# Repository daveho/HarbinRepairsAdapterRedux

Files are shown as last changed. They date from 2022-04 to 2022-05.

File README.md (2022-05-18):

# Improved Harbin Repairs Adapter PCBs

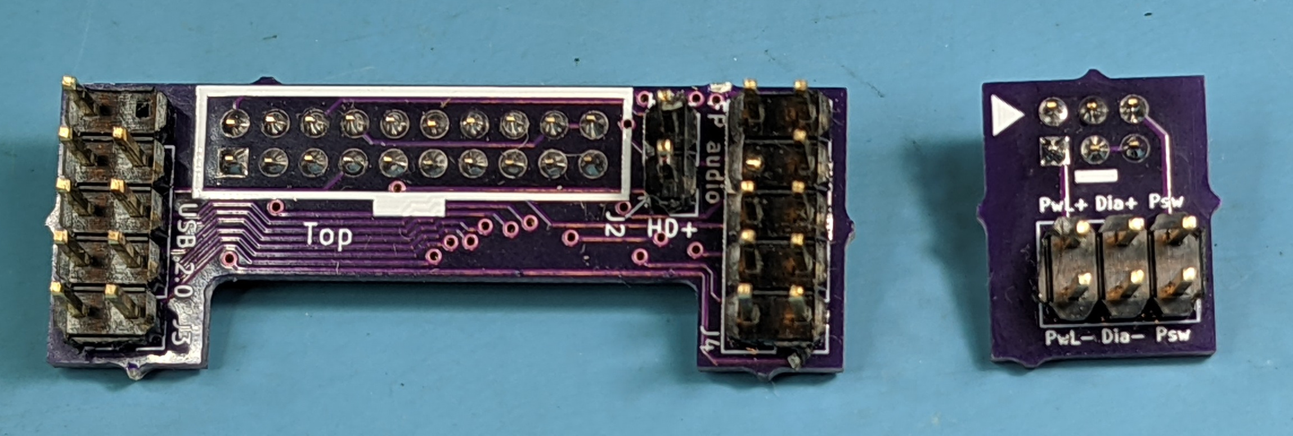
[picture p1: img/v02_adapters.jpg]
photo of the adapter PCBs


This repo has modified versions of the
[Harbin Repairs](https://harbinrepairs.com/) adapter PCBs
for Haswell Optiplex systems (Optiplex 7020, Optiplex 9020,
Optiplex XE2, and Precision T1700.)

These PCBs allow Optiplex motherboards to be used in a standard
Micro-ATX case, which (in my opinion) is a very nice option for
building a useful PC from inexpensive and widely available components
salvaged from decommissioned Dell systems.

I modified the 5/6 pin power switch adapter and the 20 pin front-panel
USB2, audio, and HD LED adapter so that they would not hang off of the
edge of the motherboard. This allows them to be used in cases where
the motherboard is physically close to the edge of the case or
the power supply.

Examples of cases in which the original PCBs don't work:

* Rosewill LINE-M (power switch PCB doesn't fit because the
  power supply obstructs it)
* Compaq Presario SR2000 series (20 pin front-panel PCB doesn't
  fit because the bottom of the case obstructs it)

## Why I created a completely new repository

Originally I forked the Harbin Repairs repository, which is
here: <https://github.com/HarbinRepairs/Dell-Optiplex-MB-Header-Adapters>

However, I was not able to make changes to the KiCad project for
the 20 pin adapter PCB because the filenames are too long.
Also, when I tried to open the PCB design for the 20 pin adapter,
I could not see any traces, but the rats nest also showed that
there were no unconnected nets. I think this might have something
to do with an autorouter being used in the original PCB design.
In any case, I created an entirely new PCB design for this adapter,
based on the original schematic.

## Do they work?

Yes, they do work. I made a video in which I populate and test both
adapters: <https://youtu.be/Dam3fpzKUps>

## Fabrication and construction

I used [OSHPark](https://oshpark.com/) to fabricate the PCBs. It is
incredibly simple: just upload the `kicad_pcb` files, then place your
order.

When you have the PCBs, you will need the following parts:

Part | Needed for | Note
---- | ---------- | ----
[0805 470 Ohm surface-mount resistor](https://www.digikey.com/en/products/detail/te-connectivity-passive-product/CRG0805F470R/2380909) | 20-pin adapter | Exact value is not critical
[2x10 2mm female header](https://www.digikey.com/en/products/detail/sullins-connector-solutions/NPPN102AFCN-RC/804795) | 20-pin adapter | connects to 2x10 male header on motherboard
2x5 2.54mm male header | 20-pin adapter | HD audio: remove second pin in bottom row
2x5 2.54mm male header | 20-pin adapter | USB2: remove first pin in top row
1x2 2.54mm male header | 20-pin adapter | HD LED
[2x3 2mm female header](https://www.digikey.com/en/products/detail/sullins-connector-solutions/NPPN032AFCN-RC/804788) | 5/6-pin adapter | connects to 5 pin header on motherboard
2x3 2.54mm male header | 5/6-pin adapter | power switch, power LED, diagnostic LED

I have linked to 2mm headers and a resistor on Digi-Key that I believe are correct.
However, I bought the 2x10 and 2x3 2mm female headers on Ebay, and I used a resistor
I already had on hand. It likely that any 2mm female headers you find will work.

The 2.54mm pin headers are just standard ones with square pins. You should be able
to find them just about anywhere.

## License

These modified PCBs are licensed under the GPL-3.0 license (the same
as the original PCBs.)

You can send feedback to me at <mailto:david.hovemeyer@gmail.com>.

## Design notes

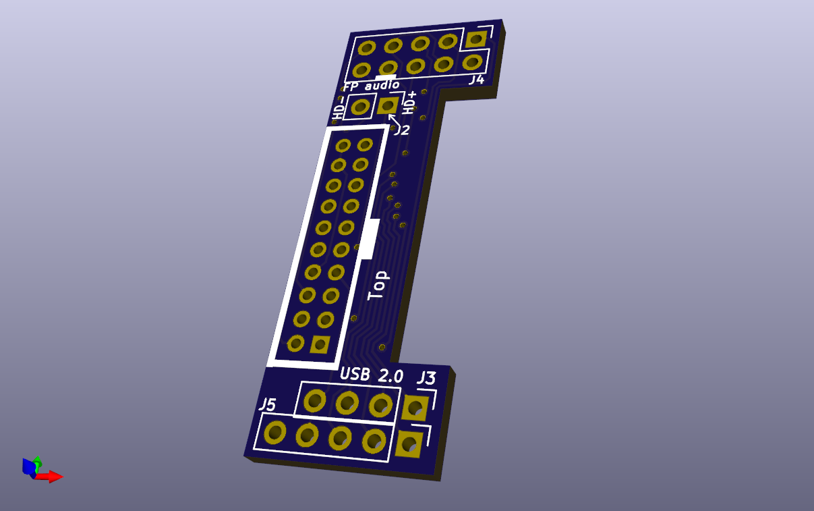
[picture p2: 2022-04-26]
img/20pin_frontpanel_v0_2.png

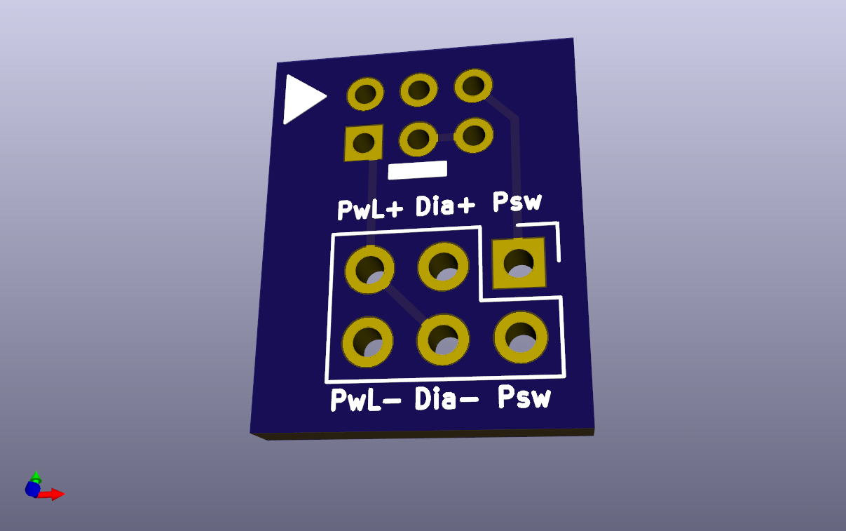
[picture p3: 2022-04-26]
img/6pin_power_v0_2.png

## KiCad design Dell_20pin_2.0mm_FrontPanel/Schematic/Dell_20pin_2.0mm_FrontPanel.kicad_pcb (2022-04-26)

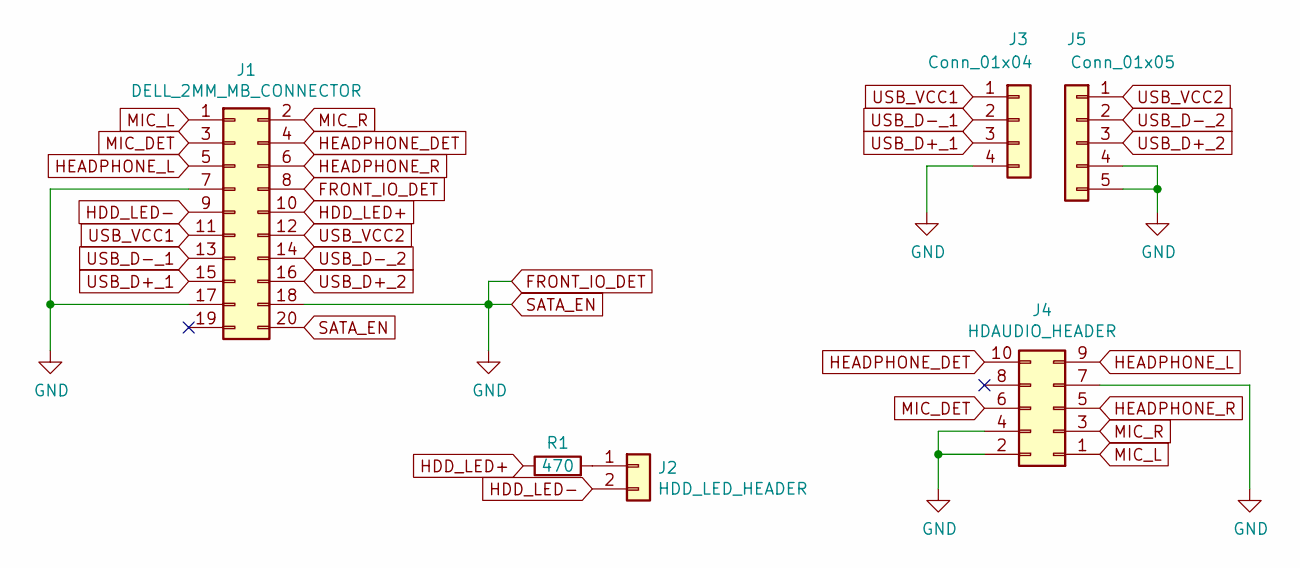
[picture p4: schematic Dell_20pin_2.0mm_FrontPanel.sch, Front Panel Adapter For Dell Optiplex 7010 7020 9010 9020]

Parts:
J1: DELL_2MM_MB_CONNECTOR; PinSocket_2x10_P2.00mm_Vertical
J2: HDD_LED_HEADER; PinHeader_1x02_P2.54mm_Vertical
J3: Conn_01x04; PinHeader_1x04_P2.54mm_Vertical
J4: HDAUDIO_HEADER; PinHeader_2x05_P2.54mm_Vertical
J5: Conn_01x05; PinHeader_1x05_P2.54mm_Vertical
R1: 470; R_0805_2012Metric

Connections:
FRONT_IO_DET: J1.7, J1.8, J1.17, J1.18, J1.20, J3.4, J4.2, J4.4, J4.7, J5.4, J5.5
HDD_LED+: J1.10, R1.1
HDD_LED-: J1.9, J2.2
HEADPHONE_DET: J1.4, J4.10
HEADPHONE_L: J1.5, J4.9
HEADPHONE_R: J1.6, J4.5
MIC_DET: J1.3, J4.6
MIC_L: J1.1, J4.1
MIC_R: J1.2, J4.3
unnamed: J2.1, R1.2
USB_D+_1: J1.15, J3.3
USB_D+_2: J1.16, J5.3
USB_D-_1: J1.13, J3.2
USB_D-_2: J1.14, J5.2
USB_VCC1: J1.11, J3.1
USB_VCC2: J1.12, J5.1

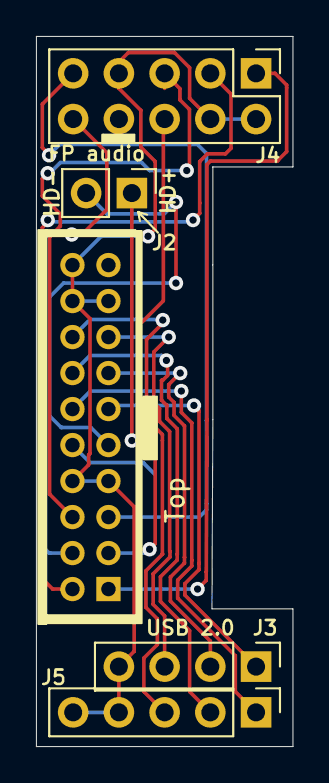
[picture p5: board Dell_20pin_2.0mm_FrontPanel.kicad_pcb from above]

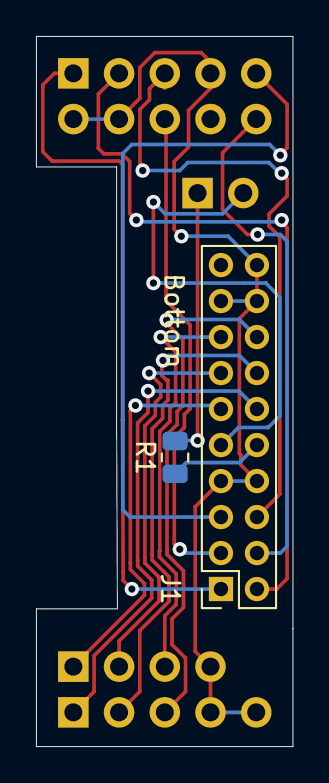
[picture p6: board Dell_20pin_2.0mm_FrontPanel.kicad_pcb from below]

Board: 2 copper layers, 14.2 x 39.4 mm, 6 parts (2 on the bottom side), 16 nets.

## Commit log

2022-02-08 create new repo and projects
    The original Harbin Repairs repo has some issues that
    make it difficult to work with: very long filenames,
    spaces in filenames, etc.
    This repo contains my modified versions of the adapter
    PCBs, but with changes to make the files easier to work
    with, and to make the projects more self-contained.
    [Dell_5-6pin_2.0mm_Power.dsn, Dell_5-6pin_2.0mm_Power.kicad_pcb, Dell_5-6pin_2.0mm_Power.sch]
2022-02-08 import original 20pin PCB project
    [Dell_20pin_2.0mm_FrontPanel.dsn, Dell_20pin_2.0mm_FrontPanel.kicad_pcb, Dell_20pin_2.0mm_FrontPanel.sch]
2022-02-08 start new PCB design
    For some reason, when I load the original one in
    pcbnew, it does not show any tracks, but also does
    any rats nest connections.
    [Dell_20pin_2.0mm_FrontPanel.kicad_pcb]
2022-02-08 placed components
    Note that I still need to make a cutout to avoid
    obstructing the connector for the temperature sensor.
    [Dell_20pin_2.0mm_FrontPanel.kicad_pcb]
2022-02-08 added cutout for temp sensor connector
    also, set up design rules for OSHPark, and start
    routing
    [Dell_20pin_2.0mm_FrontPanel.kicad_pcb]
2022-02-08 all traces routed?
    [Dell_20pin_2.0mm_FrontPanel.kicad_pcb]
2022-04-26 move front-panel USB2 connector
    In the previous version, the part of the PCB where the
    USB2 connector was located bumped up against a capacitor
    on the motherboard. In the revised version, the
    USB2 connector is moved to the "bottom" of the adapter
    PCB, so the cutout can extended to accommodate the
    capacitor.
    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
    [Dell_20pin_2.0mm_FrontPanel.kicad_pcb]
2022-04-26 redesigned to move the connectors further apart
    In the previous version, the pins of the 2x3 2.54mm
    connector bumped up against the shroud of the 2x3 2mm
    connector on the motherboard. (Not so much that the
    adapter didn't work, but still not ideal.)
    The revised version reorients the 2x3 2.54mm header and
    moves it a bit further from the 2mm connector.
    [Dell_5-6pin_2.0mm_Power.kicad_pcb]
2022-04-26 it helps if you actually route the signals, duh :-)
    [Dell_5-6pin_2.0mm_Power.kicad_pcb]
2022-05-18 indicate top and bottom on silkscreen
    [Dell_5-6pin_2.0mm_Power.kicad_pcb]
